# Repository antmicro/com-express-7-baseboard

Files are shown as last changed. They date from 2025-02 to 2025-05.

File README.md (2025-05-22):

# COM Express 7 Baseboard

Copyright (c) 2024-2025 [Antmicro](https://www.antmicro.com)




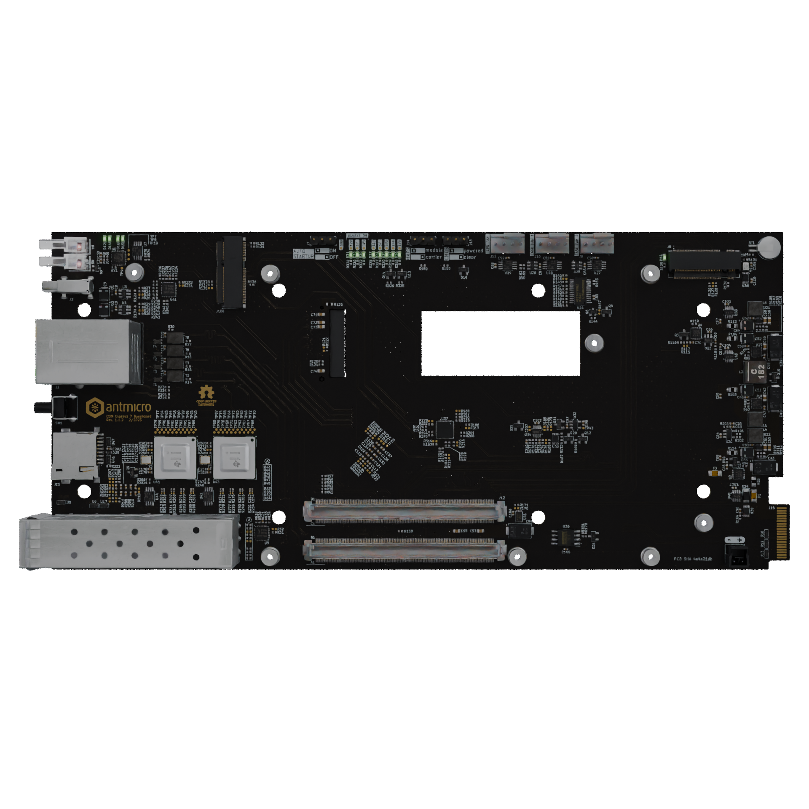
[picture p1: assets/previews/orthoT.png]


## Overview

This project contains open hardware design files for a baseboard supporting COM Express 7 modules.
The board breaks-out major communications and peripheral interfaces provided by the standard.
It also provides a backplane connector which makes it possible to integrate this board into larger systems.

## Key features

* Two SFP+ 10G Ethernet ports
* OCuLink PCIe x4 connector
* Two USB 3.0 type A ports
* Gigabit RJ45 connector
* Singular +12V supply voltage
* USB-C console output
* Two M.2 key M with PCIe x4
* M.2 key E
* SD card connector
* Backplane connector with PCIe, USB and UART console
* Temperature and fan monitor/controller with 3 12V fan connectors
* LEDs for status indication
* Board power/current monitors
* Board EEPROM and support for carrier MAFS BIOS

## Project structure

The main directory contains KiCad PCB project files, a LICENSE, and a README.
The remaining files are stored in the following directories:

* `doc` - contains board schematic and documentation
* `assets` - contains visual assets for showcasing this design on [Open Hardware Portal](https://openhardware.antmicro.com/boards/com-express-7-baseboard/?tab=features&view=top-ortho).

## Licensing

This project is published under the [Apache-2.0](LICENSE) license.

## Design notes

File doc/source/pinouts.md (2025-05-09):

# Pinouts

## Backplane connector ([`J16`](#J16))

```{csv-table}
:header: >
:    "Pin no.", "Net", "Pin no.", "Net"
:widths: 5, 20, 5, 20

"1", "12V","2", "12V"
"3", "12V","4", "12V"
"5", "12V","6", "12V"
"7", "12V","8", "12V"
"9", "12V","10", "12V"
"11", "GND","12", "GND"
"13", "GND","14", "GND"
"15", "GND","16", "GND"
"17", "PCIe TX0+","18","PCIe RX0-"
"19", "PCIe TX0-","20","PCIe RX0+"
"21", "GND","22", "GND"
"23", "PCIe TX1+","24","PCIe RX1+"
"25", "PCIe TX1-","26","PCIe RX1-"
"27", "GND","28", "GND"
"29", "PCIe REF.CK+","30", "!PERST"
"31", "PCIe REF.CK-","32", "!PRSNT"
"33", "GND","34", "GPIO"
"35","USB.D+","36","UART.RX"
"37","USB.D-","38","UART.TX"
"39", "GND","40", "GND"
```

## Fan connector ([`J9`](#J9), [`J10`](#J10), [`J11`](#J11))

```{csv-table}
:header: >
:    "Pin no.", "Net"
:widths: 5, 20

"1", "GND"
"2", "12V"
"3", "TACH"
"4", "PWM"
```

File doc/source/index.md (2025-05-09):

# {{project}}

```{toctree}
:maxdepth: 3

introduction
getting_started
power_supply
peripherals
pinouts
```

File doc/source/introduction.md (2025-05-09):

# Introduction

The `Baseboard` supports COM Express `Type 7` modules. The board breaks out major communications and peripheral interfaces as defined by the COM Express standard. It features front panel connectors for cable interfaces and a backplane edge connector designed for integrating the board into larger systems.

One of the supported COM Express Type 7 modules is the `SolidRun LX2160A`. It features 16 Arm Cortex-A72 processors, 4 x 10GbE and 18x PCIe Gen 3.0 lanes and is fully supported by Linux.

The board design files were created in `KiCad 8.x`.
You can find out more about the `COM Express 7 Baseboard` by visiting Antmicro's portals listed below:

* [Open Hardware Portal](https://openhardware.antmicro.com/boards/com-express-7-baseboard/)
* [System Designer](https://designer.antmicro.com/hardware/devices/com_express_7_baseboard_with_lx2160a)
* [Open Source Portal](https://opensource.antmicro.com/projects/com-express-7-baseboard/)
 
They provide 3D renders and the board [stackup definition](https://openhardware.antmicro.com/boards/com-express-7-baseboard/?view=top-ortho&tab=stackup), as well as [an interactive preview](https://openhardware.antmicro.com/boards/com-express-7-baseboard/?view=top-ortho&amp%3Btab=stackup&tab=preview) of the board schematic.
A [PDF schematic](../com-express-7-baseboard-schematic.pdf) of the board is also available.

## Block diagram

<iframe src="_static/COM_Express_baseboard_VSD_graph.html" style="border:0px" height="800px" width="100%" title="COM Express 7 baseboard graph"></iframe>

## IO map 

A map of on-board connectors, status LEDs, control buttons and I/O interfaces is provided below.

:::{figure-md}
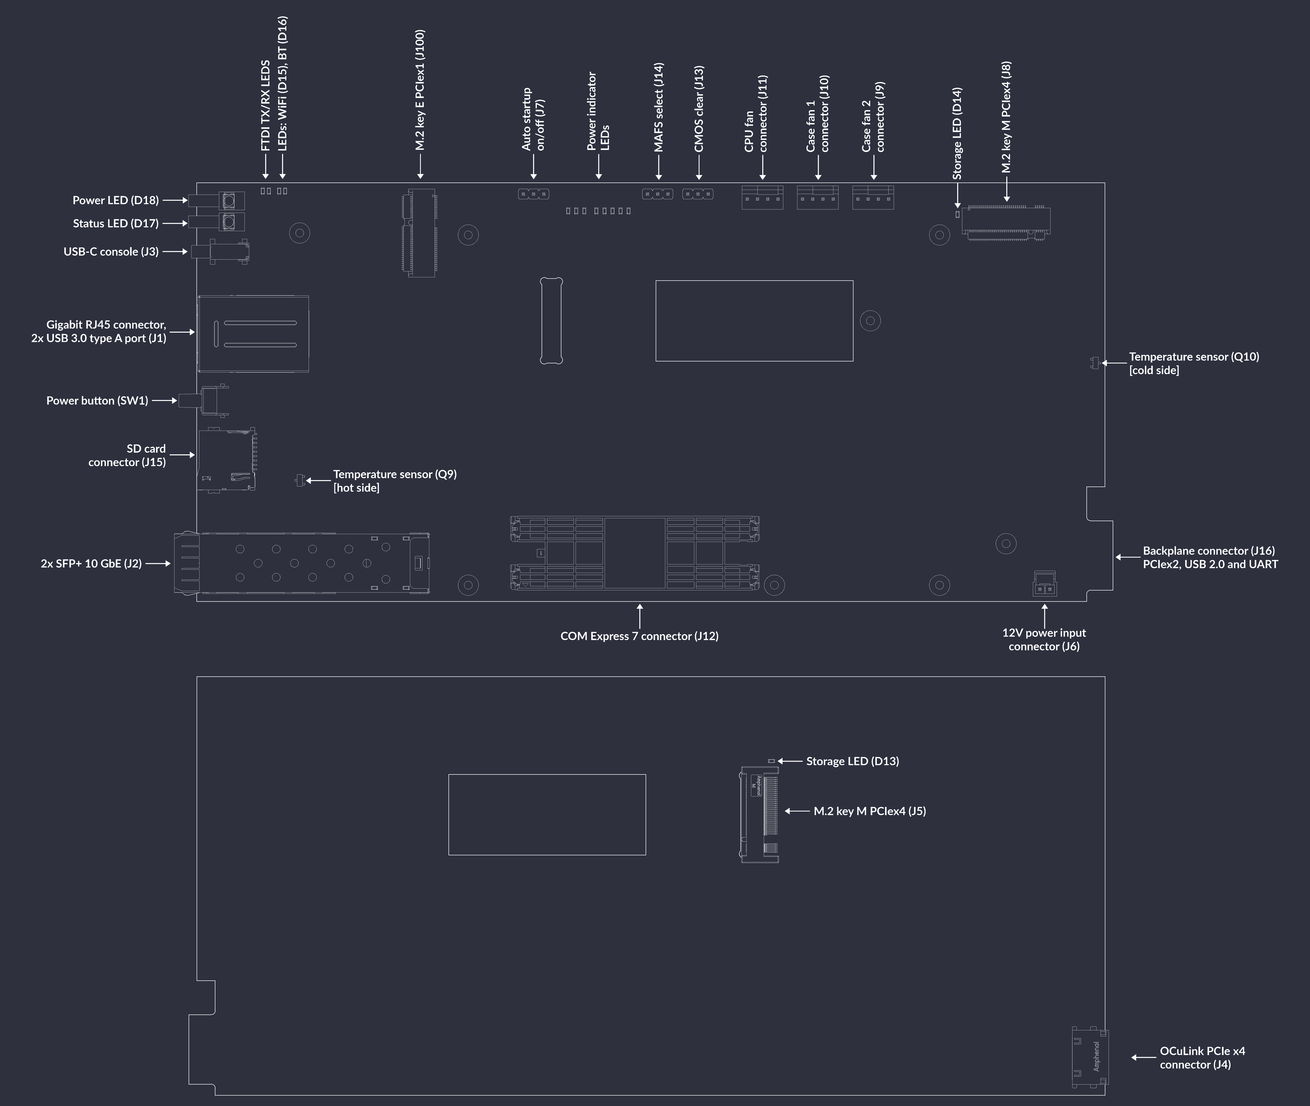
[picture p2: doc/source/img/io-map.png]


COM Express 7 Baseboard interface map
:::

## Power
 
`COM Express 7 Baseboard` can be powered with a DC voltage via the on-board locking DC connector ([`J6`](#J6)) with Molex Nano-Fit plug, or backplane PCB-edge connector ([`J16`](#J16)).
More details in [Power supply](./power_supply.md) section.

## Available interfaces and features

- 2x SFP+ 10 Gigabit Ethernet port ([`J2`](#J2))
- Gigabit Ethernet RJ45 connector ([`J1A`](#J1))
- OCuLink PCIe x4 connector ([`J4`](#J4))
- USB-C console ([`J3`](#J3))
- USB 3.0 - two type A ports: ([`J1B`](#J1)) and ([`J1C`](#J1))
- 2x M.2 2280 key M connector with PCIe x4 ([`J5`](#J5)) and ([`J8`](#J8))
- M.2 2230 key E connector with PCIe x1 and USB ([`J100`](#J100))
- Backplane PCB edge connector ([`J16`](#J16)) with PCIe x2, USB 2.0, UART console and 1x GPIO
- SD card connector ([`J15`](#J15))
- Board EEPROM and support for carrier MAFS BIOS
- Power button ([`SW1`](#SW1))
- Fan connectors: CPU fan ([`J11`](#J11)) + 2x case fan ([`J10`](#J10)) and ([`J9`](#J9))
- Board temperature sensors (`Q9`) and (`Q10`)
- 2x RGB LED for status indication

## Mechanics

The `COM Express 7 Baseboard` PCB is `227.5`x`104.0` millimeters (WxL) which translates into `8.96`x`4.09` inch.
The overall height of the set depends on the attached cooling module.

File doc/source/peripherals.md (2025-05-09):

# Peripherals

## Selection jumpers

- **Master Attached Flash Sharing location selection**

  MAFS location can be set to be on `module` or on `carrier`, using ([`J14`](#J14)) jumper.
  During normal operation, it is set to `module`.

- **Clear CMOS**

  Using ([`J13`](#J13)) jumper, RTC on COM Express 7 can be cleared.
  During normal operation, it is set to `powered`, which provides power to the RTC.

Jumpers positions for normal operation are shown on the render bellow.
:::{figure-md}
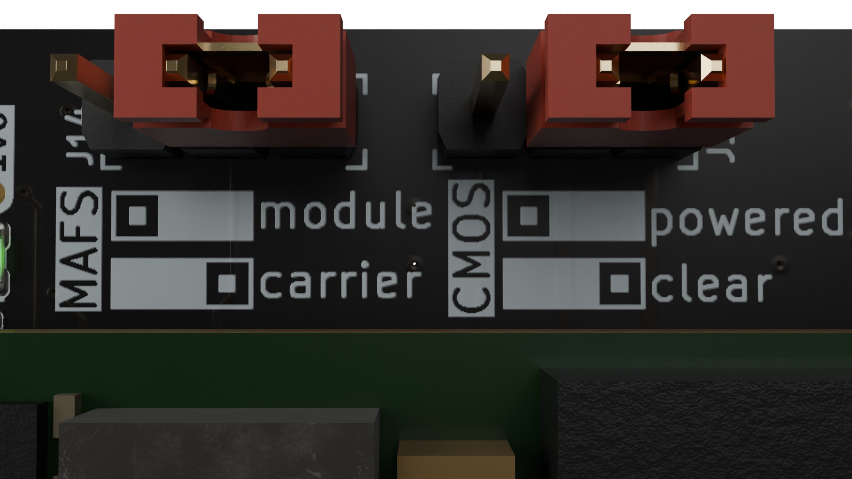
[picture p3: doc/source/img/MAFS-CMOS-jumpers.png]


COM Express 7 Baseboard MAFS and CMOS jumpers default configuration.
:::

## Fan control

- CPU fan ([`J11`](#J11)connector) is controlled by the COM Express 7 SoM<!-- (pins `B101`(PWM) and `B102`(TACH) of [`J12`](#J12))-->.
- Case fans ([`J10`](#J10) and [`J9`](#J9) connectors) can either share PWM speed control with CPU fan or be individually controlled by `ADT7476AARQZ` (`U24`).

## Board temperature measurement

Board temperature can be monitored with `ADT7476AARQZ` (`U24`) in three locations on the `COM Express 7 Baseboard`, using internal to the IC temperature sensor and two external sensors: (`Q9`) and (`Q10`). Their location is shown on the picture bellow.

:::{figure-md}
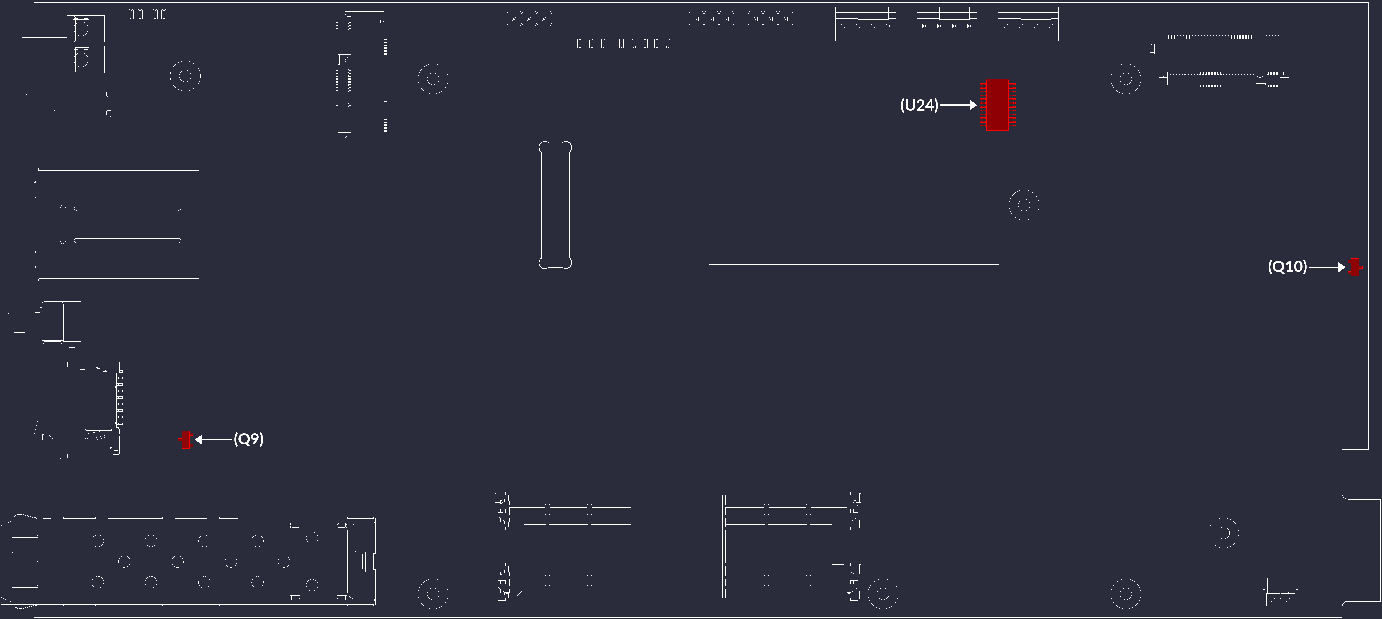
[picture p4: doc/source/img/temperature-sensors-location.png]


COM Express 7 Baseboard location of temperature sensors.
:::

## SFI / KR

1 HS channel needs to be configured (e.g. CH A) for 10G-KR, configure the other HS channel for XFI per the attached instructions,  and use Data Switch to connect CH A to CH B (DST_CONTROL_1/2 registers) [(attached instructions)](https://e2e.ti.com/support/interface-group/interface/f/interface-forum/703878/tlk10034-10gbase-kr-to-sfi-sfp).

By using `OR` resistors, `SFI` can be directly connected to `10GBase-KR` pins on `COM Express Type 7`, eliminating the need for the `TLK10232CTR` ICs. This configuration is intended for modules that support SFI-compatible interfaces on 10GBase-KR pins, such as the `SolidRun LX2160A`.

````{tab} Default configuration

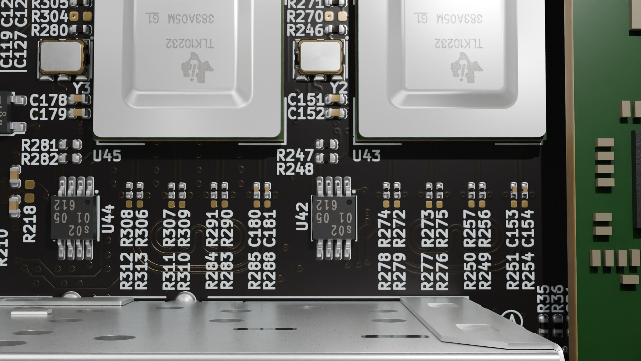
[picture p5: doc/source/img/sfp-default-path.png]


````
````{tab} TLK10232CTR bypassed

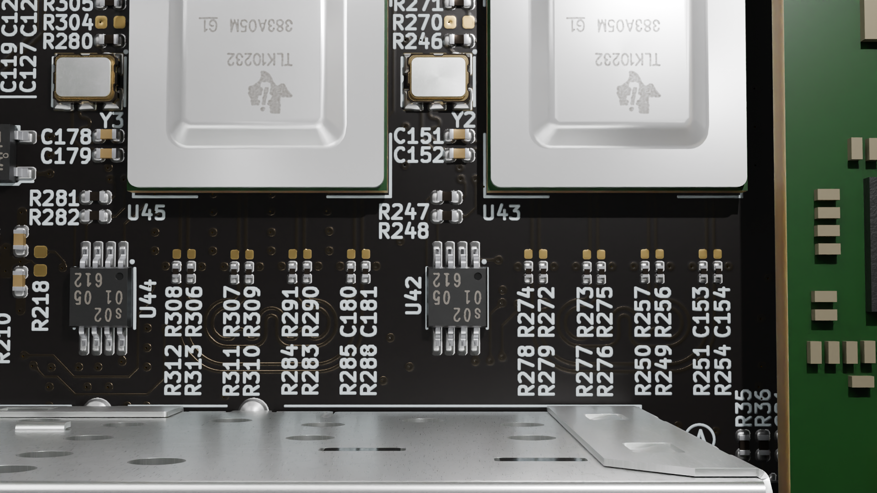
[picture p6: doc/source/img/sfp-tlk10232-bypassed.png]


````

## 10GbE on backplane connector

If `LX2160A` SoM is used, `PCIe B3x4` on the backplane connector ([`J16`](#J16)) can be configured as `10G-KR`.

## GPIO Expanders
Two `PCA9539AHF` GPIO expanders are connected to the I2C `bus 1` of the SoM:

- Expander at Address `0x74` (`U41`)

| **Pin**  | **Function** | **Details** |
|---|---|---|
| P0_0 | RGB LED - Green | `D17` |
| P0_1 | RGB LED - Blue | `D17` |
| P0_2 | RGB LED - Red | `D17` |
| P0_3 | USB Power Enable - `EN_1` | ([`J1B`](#J1)) |
| P0_4 | USB Power Enable - `EN_2` | ([`J1C`](#J1)) |
| P0_5 | `!PRSNT` / `!CPRSNT0` | PCIe Redriver / OCuLink |
| P0_6 | `GPIO` | Backplane Connector ([`J16`](#J16)) |
| P0_7 | `!PRSNT` | Backplane Connector ([`J16`](#J16)) |

- Expander at Address `0x75` (`U5`)

| **Pin**  | **Function** | **Details** |
|---|---|---|
| P0_0 | SFP0 LED - Yellow | `J2` |
| P0_1 | SFP0 LED - Green | `J2` |
| P0_3 | SFP1 LED - Yellow | `J2` |
| P0_4 | SFP1 LED - Green | `J2` |

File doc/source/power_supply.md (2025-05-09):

# Power supply

## Power input connectors
The `COM Express 7 Baseboard` supports two power supply scenarios: 

* `DC locking connector` ([`J6`](#J6)) which accepts a 2-wire `Molex Nano-Fit` plug.

  This is the easiest and most recommended solution for starters.
  You can use an off-the-shelf Nano-Fit Cable assembly (Molex/[451300203](https://www.molex.com/en-us/products/part-detail/451300203)) or build a custom one from a Nano-Fit receptacle (Molex/[1053071202](https://www.molex.com/en-us/products/part-detail/1053071202)) and pre-crimped wires (Molex/[797582130](https://www.molex.com/en-us/products/part-detail/797582130)). 
  The COM Express 7 Baseboard can be powered with a benchtop PSU or AC/DC wall adapter providing 12V DC with at least 60W.
  If you are using a DC locking connector - please observe the polarity marked in the render below.

:::{figure-md}
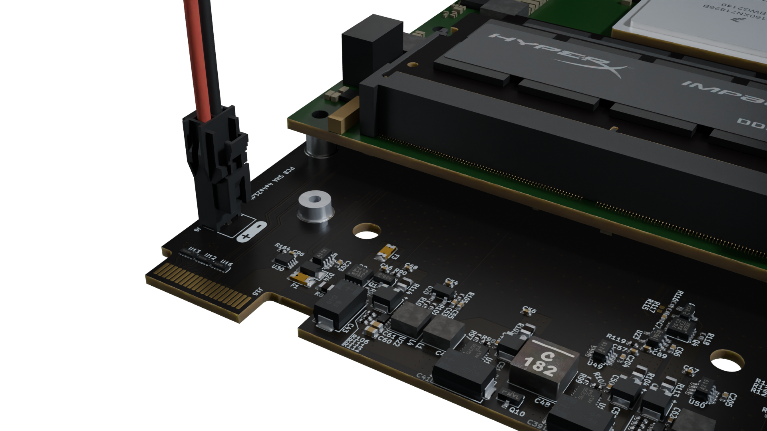
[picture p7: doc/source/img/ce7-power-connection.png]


COM Express 7 Baseboard DC power connection with polarity marking (red: VCC, black: GND).
:::

* `Backplane PCB-edge connector` ([`J16`](#J16)) is designed to interface with `Samtec HSEC8 2x20 HSEC8-120-01-S-D-EM2` female connector.
  This connector has the same electrical requirements as the DC locking connector, since they are directly connected with each other on the baseboard.
  See the [Pinouts](./pinouts.md) section for the connector pinout.

These inputs are protected with a 12A fuse and 15V TVS diode. The nominal supply voltage is 12V. 
When LX2160A is used, absolute maximum is 15V and it requires 50W full system.

## Auto startup

[`J7`](#J7) jumper determines if auto startup is on/off.

When auto startup is enabled, all power rails of the `COM Express 7 Baseboard` turn on automatically after power is provided to the baseboard, and the SoM boots.

If auto startup is off, only the always on (AON) rails turn on after power is provided to the baseboard.
Then to continue the power up, power button [`SW1`](#SW1) needs to be pressed.

## Power sequence

```{md-mermaid}
graph LR
V_IN --> +12V_AON --> +5V_AON --> +3V3_AON --> Power_button/auto_startup -->  +12V --> +5V --> +3V3 --> +1V8 --> +1V0 -->|120ms| PWR_OK
```

- When 12V is supplied to the baseboard, LED [`D18`](#D18) glows red, indicating that power is connected
- After all power supplies start-up correctly, 1V0 rail will trigger `PWR_OK` line to set to high state after 120ms (the delay is created by `U20`). 
This will result in ([`D18`](#D18)) changing color from red to green, which signals successful power supply section startup.
- There is a combinational logic circuit which pulls the `PSON` net low, if the COM Express module is NOT type 7. It is determined by the state of `!TYPE0`, `!TYPE1` and `!TYPE2` signals, which come from the connected COM Express module (pins C54, C57 and D57 of [`J12`](#J12)). This will prevent the baseboard from powering up, if wrong type of COM Express module is connected.

## Power indicator LEDs

There are power indicator LEDs for every power rail (`D26`, `D27`, `D28`, `D30`, `D31`, `D32`, `D33` and `D34`) as shown on the render below.

:::{figure-md}
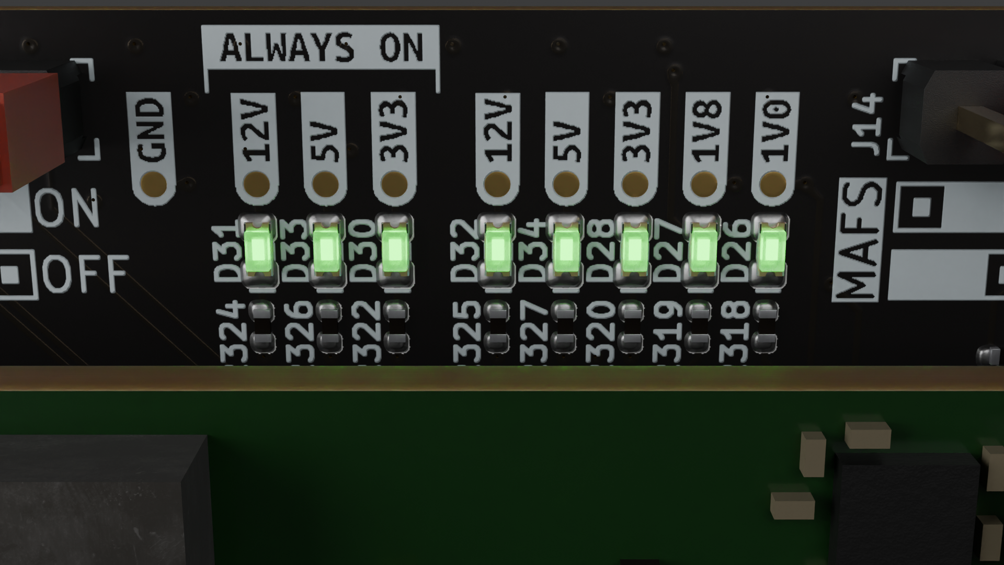
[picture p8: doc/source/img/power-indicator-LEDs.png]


COM Express 7 Baseboard power indicator LEDs.
:::

## Supply monitoring
- Three `INA219AIDCNR` ICs are used to monitor voltage and current draw on `12V` input, `3V3` and `5V` rails.
They are connected to I2C `bus 1` of the SoM. Their I2C addresses and corresponding power rails are listed below:

  | Address  | Description |
  |----------|-------------|
  | 0x40     | 12V rail    |
  | 0x41     | 3V3 rail    |
  | 0x42     | 5V  rail    |

- `ADT7476AARQZ` IC is used to monitor voltage of `1V0`, `1V8`, `3V3`, `5V0` and `12V` rails. It is also connected to I2C `bus 1` of the SoM, and its address is `0x2D`.
The voltage readings can be accessed through the following register addresses:

  | Register | Description |
  |----------|-------------|
  | 0x20     | 1V0 reading |
  | 0x21     | 1V8 reading |
  | 0x22     | 3V3 reading |
  | 0x23     | 5V  reading |
  | 0x24     | 12V reading |

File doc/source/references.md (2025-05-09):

# Image references
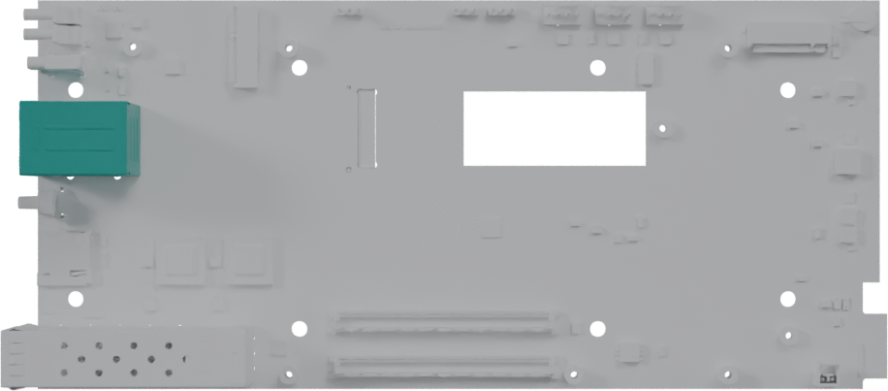
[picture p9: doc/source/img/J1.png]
```{image} img/J1.png
   :name: J1
```
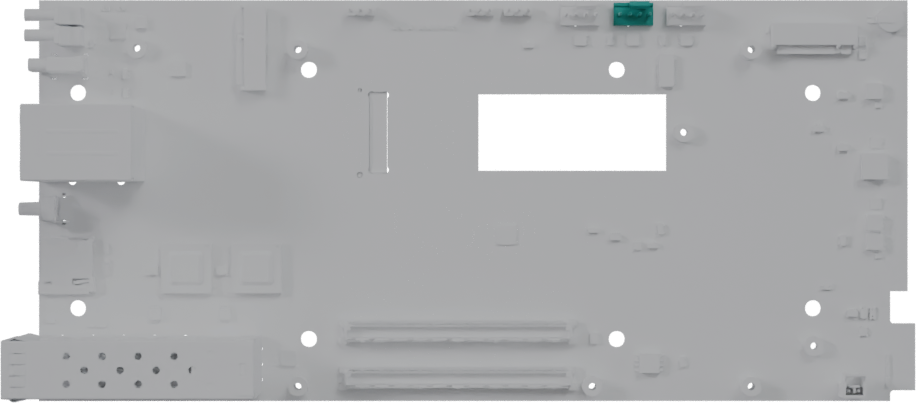
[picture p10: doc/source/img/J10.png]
```{image} img/J10.png
   :name: J10
```
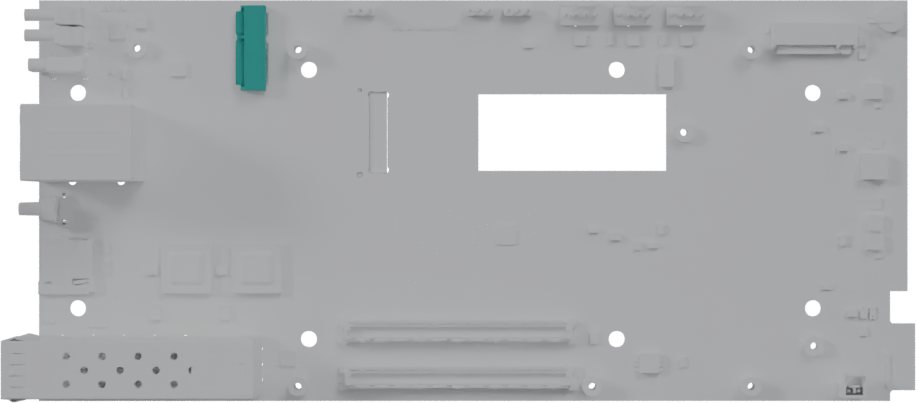
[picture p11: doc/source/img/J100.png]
```{image} img/J100.png
   :name: J100
```
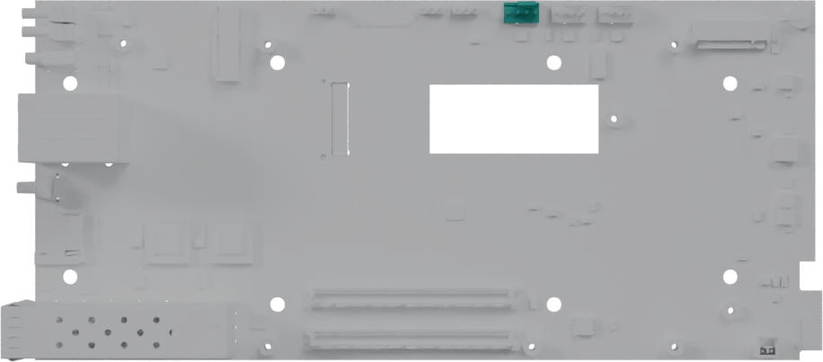
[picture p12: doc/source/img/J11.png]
```{image} img/J11.png
   :name: J11
```
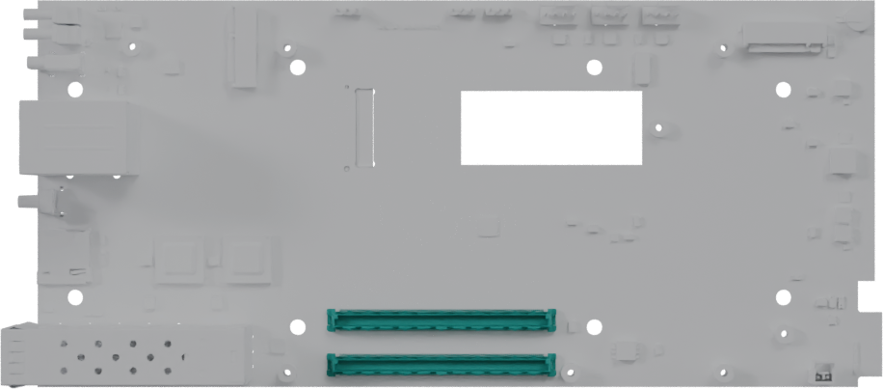
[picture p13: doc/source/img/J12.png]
```{image} img/J12.png
   :name: J12
```
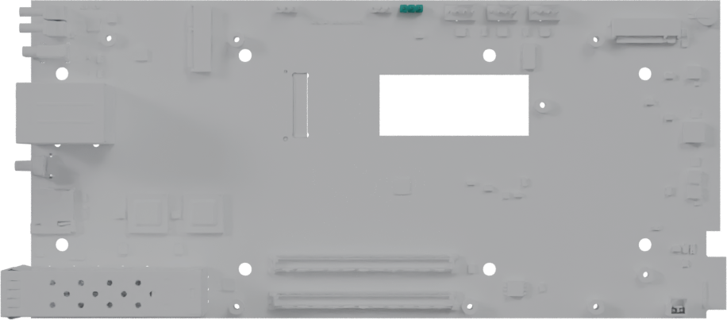
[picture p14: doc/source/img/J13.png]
```{image} img/J13.png
   :name: J13
```
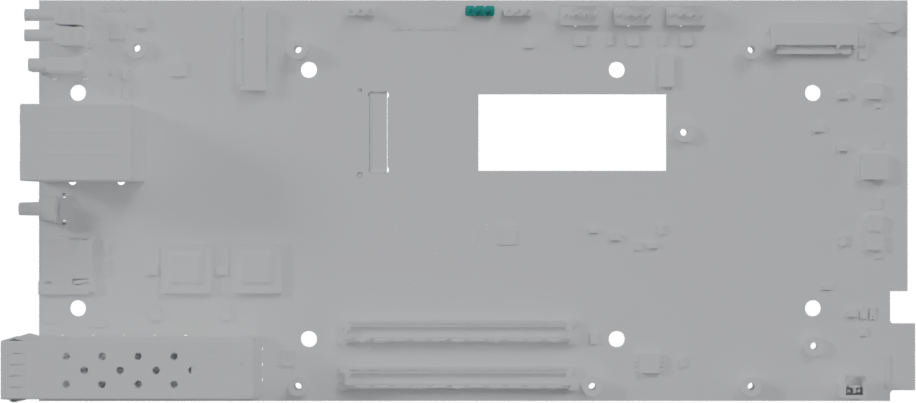
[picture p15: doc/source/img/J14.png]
```{image} img/J14.png
   :name: J14
```
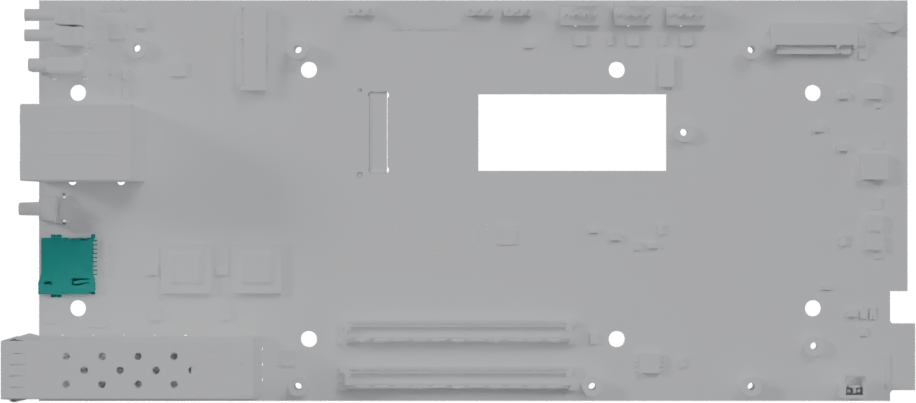
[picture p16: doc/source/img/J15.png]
```{image} img/J15.png
   :name: J15
```
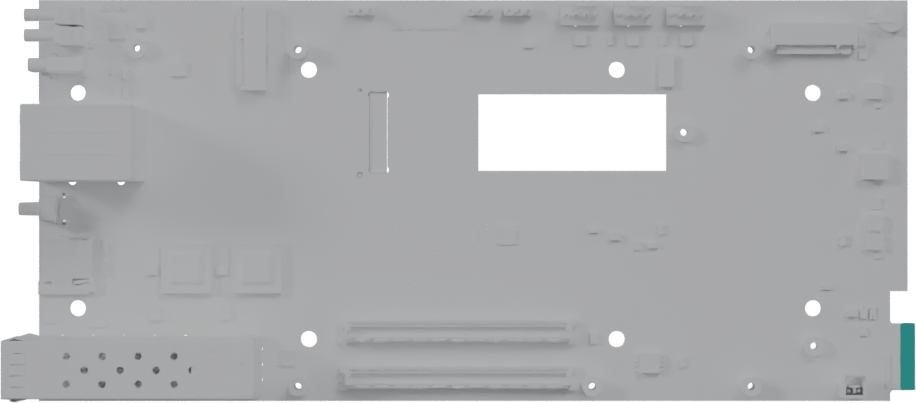
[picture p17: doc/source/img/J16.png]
```{image} img/J16.png
   :name: J16
```
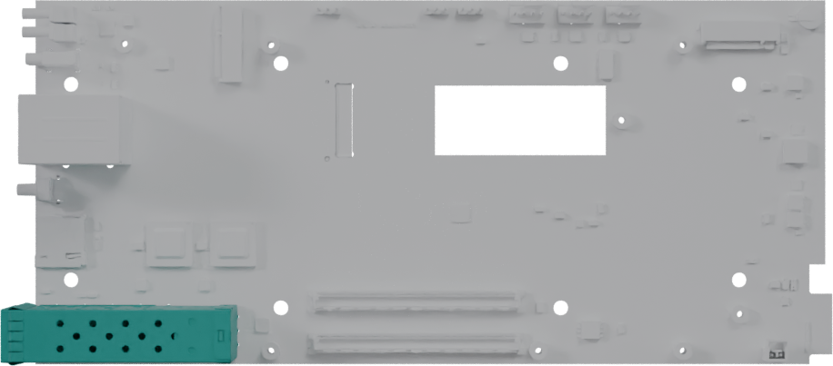
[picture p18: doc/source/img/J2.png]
```{image} img/J2.png
   :name: J2
```
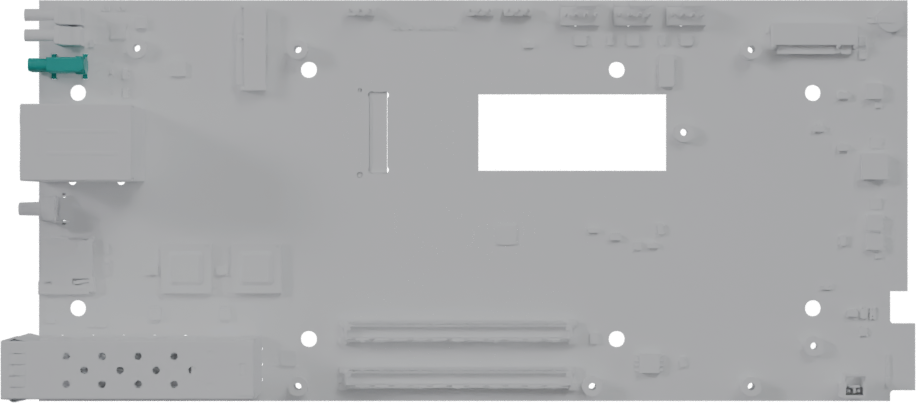
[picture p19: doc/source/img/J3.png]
```{image} img/J3.png
   :name: J3
```
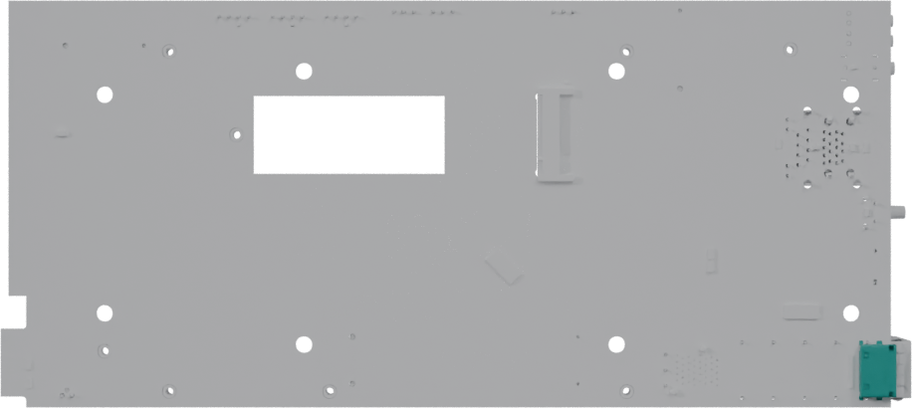
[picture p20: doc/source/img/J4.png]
```{image} img/J4.png
   :name: J4
```
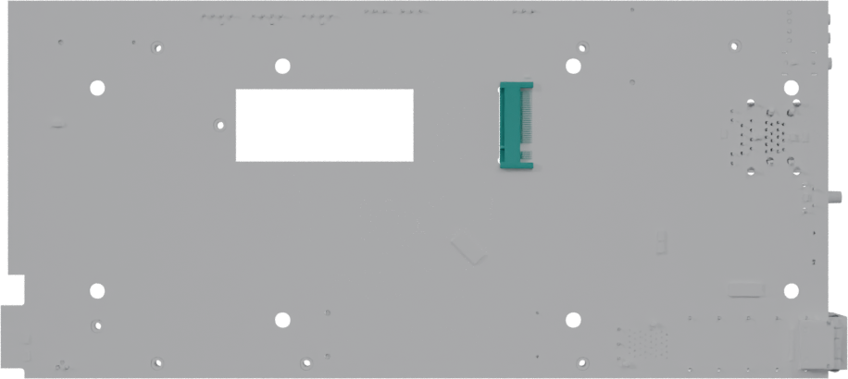
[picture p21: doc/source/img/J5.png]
```{image} img/J5.png
   :name: J5
```
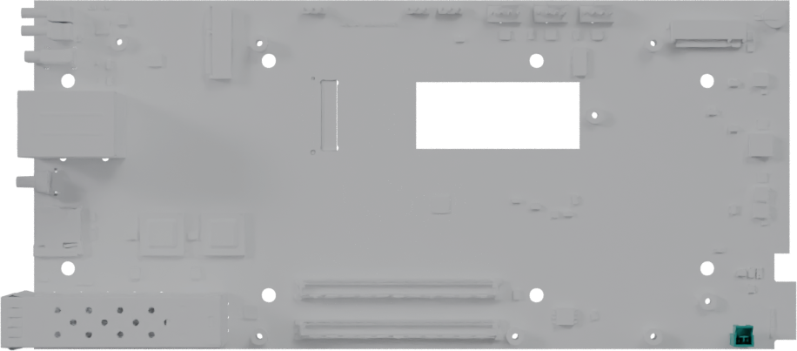
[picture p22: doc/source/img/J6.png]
```{image} img/J6.png
   :name: J6
```
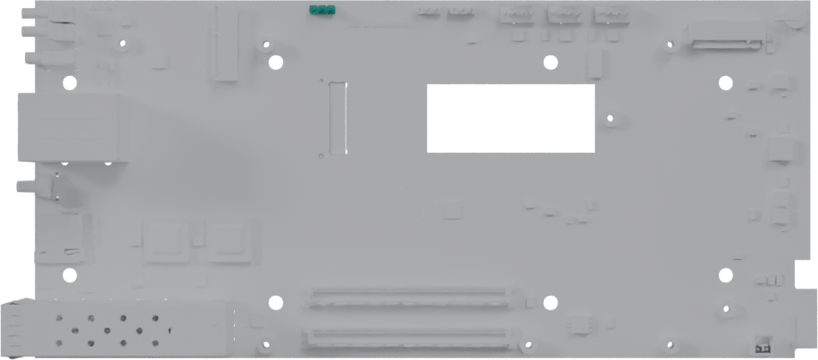
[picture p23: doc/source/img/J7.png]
```{image} img/J7.png
   :name: J7
```
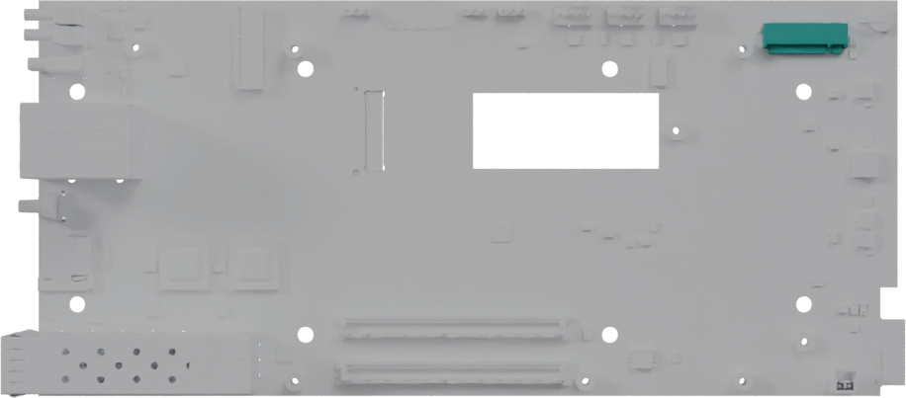
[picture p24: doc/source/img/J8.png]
```{image} img/J8.png
   :name: J8
```
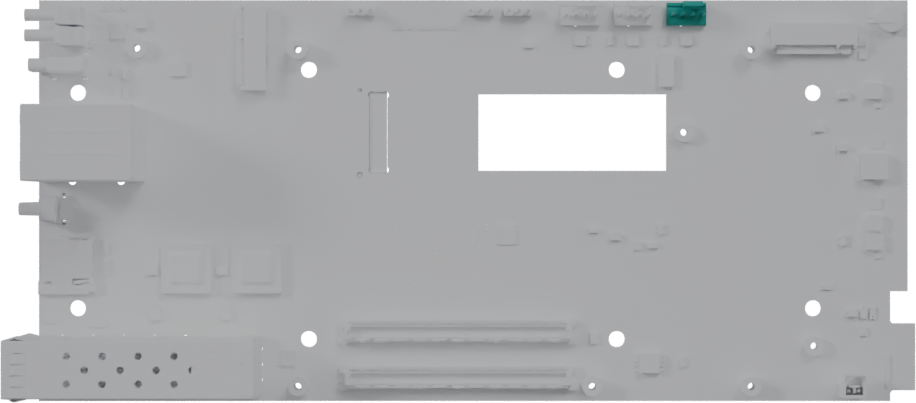
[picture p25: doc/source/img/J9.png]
```{image} img/J9.png
   :name: J9
```
```{image} img/SW1.png
   :name: SW1
```

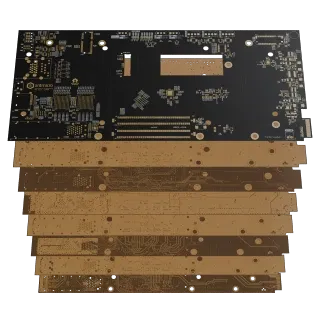
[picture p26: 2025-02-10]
assets/previews/layer1_thumbnail.webp

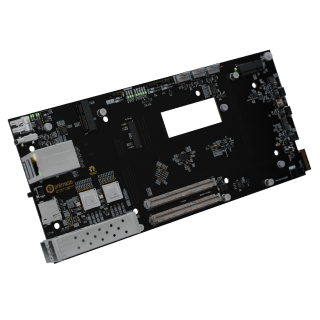
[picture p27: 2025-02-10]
assets/previews/leftT_thumbnail.png

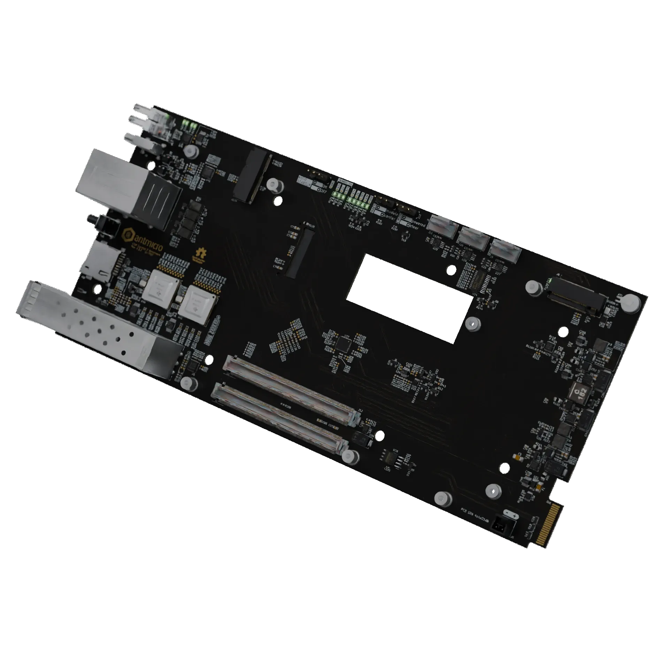
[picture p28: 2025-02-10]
assets/previews/rightT.webp

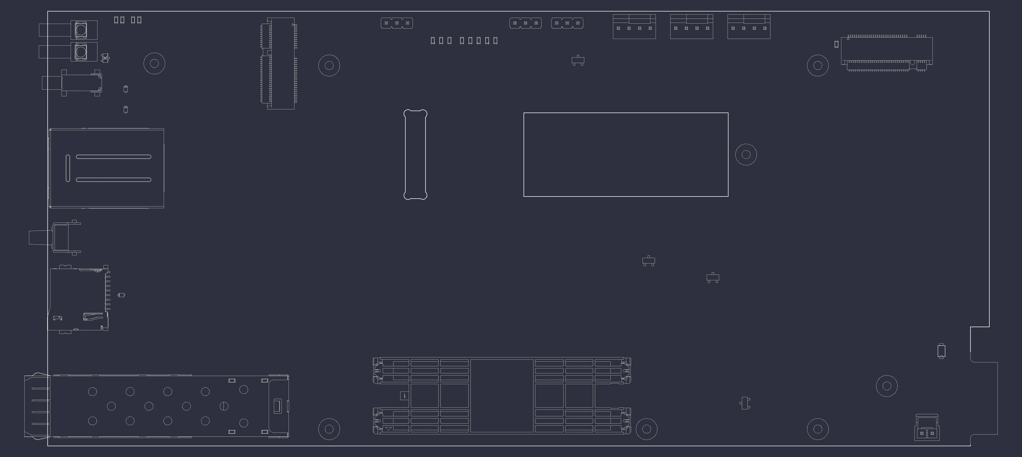
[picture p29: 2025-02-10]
assets/wireframe/wireframe_descriptions_top.webp

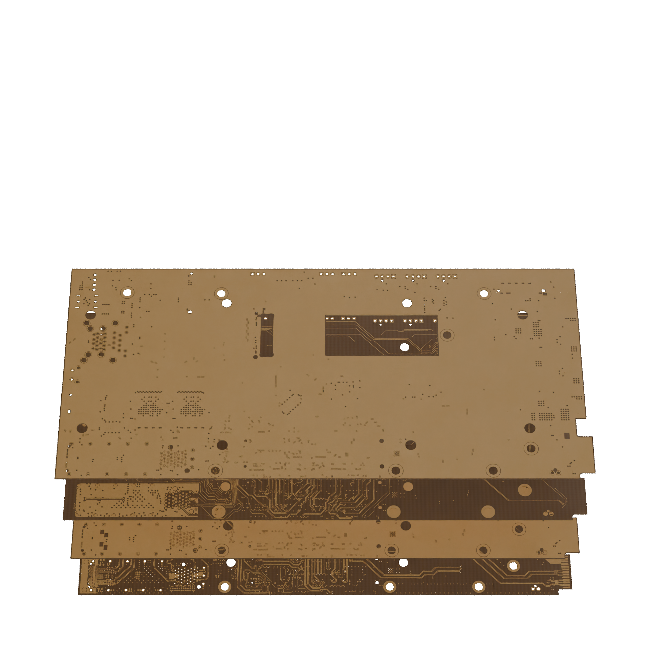
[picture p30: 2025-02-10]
assets/previews/layer6.png

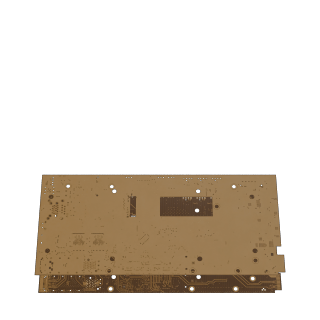
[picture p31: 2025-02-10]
assets/previews/layer8_thumbnail.png

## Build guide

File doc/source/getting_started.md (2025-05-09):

# Getting started guide

This manual will guide you through the initial setup of the open hardware `COM Express 7 Baseboard`. It describes the basic steps required to assemble the board with required peripheral accessories, write a compiled Board Support Package (BSP) to the processing module and get it booted. If you want to learn more about the `COM Express 7 Baseboard` itself, go to the [Introduction](./introduction.md) section. That section also includes an I/O map that may come in handy when locating interface connectors mentioned in this guide.
 
## Collect the hardware

To get started with the `COM Express 7 Baseboard`, you’ll need the following hardware:

### 1. COM Express 7 SoM
The `COM Express 7 Baseboard` is compatible with COM Express `Type 7` modules. The provided reference BSP has been developed for `SolidRun LX2160A` (SRX2160S01D00GE064V21C0)<!-- but it should work with other Type 7 modules as well -->.

### 2. RAM modules
You will need 2 `SO-DIMM DDR4 RAM` modules. Check the [list](https://solidrun.atlassian.net/wiki/spaces/developer/pages/197494332/LX2160A+COM+Tested+SO-DIMM+Memory) of tested modules, to help you choose appropriate RAM modules.

### 3. Power supply

The `COM Express 7 Baseboard` supports two power supply scenarios: 

* `DC locking connector` ([`J6`](#J6))
* `Backplane PCB-edge connector` ([`J16`](#J16))

More details in [Power supply](power_supply.md) chapter.

### 4. Fastening bolts

You will need five metric M2.5 (5mm long) bolts and a matching screwdriver to mount the SoM to the baseboard.
All mechanical fastening points located on the board support bolts with metric M2.5 thread (ISO 7045).

### 5. Micro SD card

Micro SD card with capacity of at least 4GB is needed, to transfer the BSP image to the baseboard.

### 6. Host PC

You will need a computer running Linux for flashing the reference BSP image to the SD card. 
The BSP flashing instructions provided below were verified with Debian based systems.
You may need to introduce minor adjustments for other Linux distributions.

### 7. SD card reader

You will need to be able to connect the micro SD card to your PC.
If your PC doesn't have an integrated SD card reader, you will need an external one.

### 8. Cabling

You will need a USB-C cable for connecting your PC to the USB-C port ([`J3`](#J3)) located on the baseboard.
This connection will provide access to the SoM's terminal on your PC.

Ethernet cable will be needed to provide internet connection to the `COM Express 7 Baseboard` via ([`J1A`](#J1)).

## Flash the SD card with system image

<!-- Instructions are from this [guide](https://solidrun.atlassian.net/wiki/spaces/developer/pages/197494288/HoneyComb+LX2+ClearFog+CX+LX2+Quick+Start+Guide). -->

### 1. Download a pre-built snapshot

Download this [pre-built snapshot image](https://solid-run-images.sos-de-fra-1.exo.io/LX2k/lx2160a_build/ls-5.15.71-2.2.0/2024-11-26_d5645d3/lx2160a_rev2_cex7_honeycomb_2000_700_2900_18_5_2-d5645d3.img.xz).

**NOTE:** This is a stock BSP, which doesn't support all functionalities of the `COM Express 7 Baseboard`.

### 2. Write the BSP image to the SD card

Plug the micro SD into your Linux PC. The following assumes that the micro SD is added as `/dev/sdX` and all it’s partitions are unmounted. In the terminal, run `sudo mount`, to check if the SD card is mounted. It can appear as /dev/mmcblk0p1 or /dev/sdb1 or similar. If partitions are mounted, unmount them first: `sudo umount <mount point>` (eg. `sudo umount /dev/sdc1`).
Now the image can be flashed to the SD card. 

Use this command for writing the image to an SD card (remember to use proper path to the BSP image and SD card):
`sudo xz -dc lx2160a_....img.xz | sudo dd of=/dev/sdX bs=4M conv=fsync`.

## Build your setup

To prepare the `COM Express 7 Baseboard` for initial usage, follow the steps described below: 

### 1. Install the RAM modules

Begin with installing the RAM modules on the COM Express 7 SoM.

### 2. Install the SoM

Securely attach the COM Express 7 SoM to the [`J12`](#J12) connector of the `COM Express 7 Baseboard`.
Fasten the SoM to the baseboard with five metric M2.5 (5mm long) bolts.
Remember to connect the cooling fan plug into the [`J11`](#J11) fan receptacle. 

### 3. Insert micro SD card

Insert the micro SD card containing the BSP, to the `COM Express 7 Baseboard` micro SD card slot ([`J15`](#J15)).

### 4. Select boot source

Configure the SW1 switch on the COM Express 7 SoM as shown on the image bellow.

:::{figure-md}
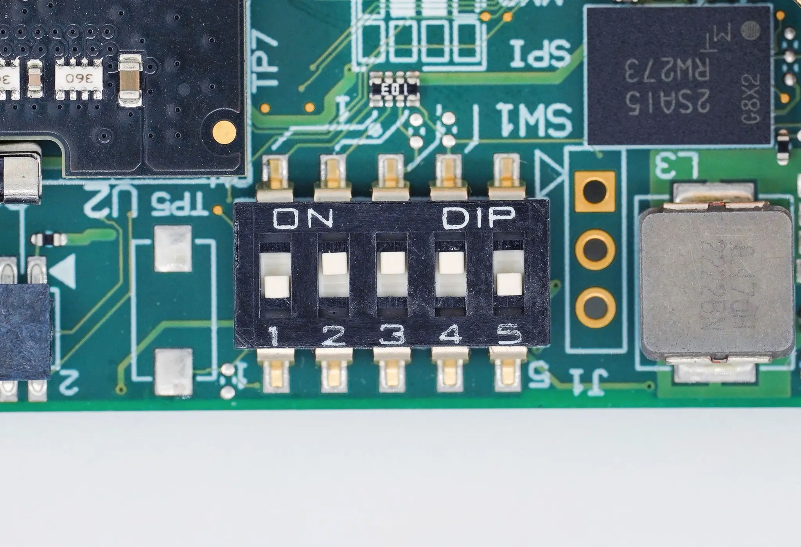
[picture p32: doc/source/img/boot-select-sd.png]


COM Express 7 boot source configured to SD card 
:::

<div align="center">

| Switch 1 | Switch 2 | Switch 3 | Switch 4 | Switch 5 |
|---|---|---|---|---|
| OFF | ON | ON | ON | x |

</div>

### 5. Connect the Ethernet port.

Connect the `COM Express 7 Baseboard` to the internet network using `RJ45` cable connected to [`J1A`](#J1) Ethernet port.

### 6. Connect the debug console

Connect the debug USB-C ([`J3`](#J3)) port to your PC. 
This should get a virtual USB/serial port registered in your system under ``/dev/ttyUSBx``.
You can check the ``lsusb`` or ``dmesg`` commands to verify if the serial bridge was enumerated properly.

:::{figure-md}
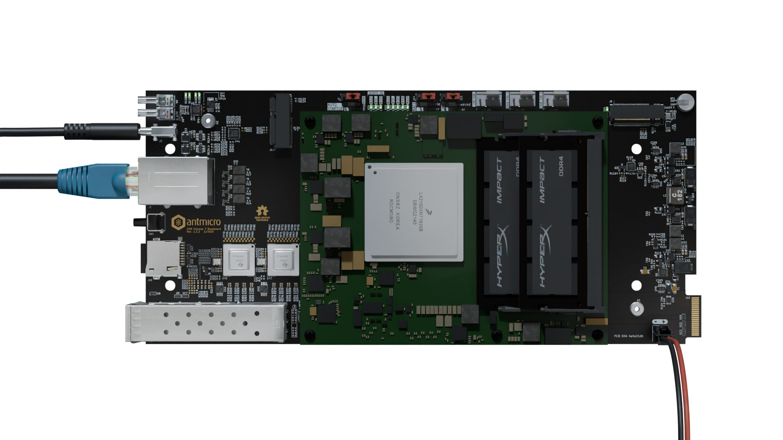
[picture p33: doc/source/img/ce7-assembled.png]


COM Express 7 Baseboard ready for flashing (SoM heat sink and fan not shown).
:::

## Flash the BSP image

The following steps will guide you through the process of flashing a precompiled Board Support Package (BSP) for the `COM Express 7 Baseboard`.

### 1. Open debug console

Whenever developing with the `COM Express 7 Baseboard`, it always makes sense to have a terminal hooked to the Debug UART on your host PC.
You can use any serial port terminal emulator for that, but we’ll use ``picocom`` in this guide.
Make sure that the [debug console USB](#connect-the-debug-console) is connected to your host PC and the USB-serial converter is enumerated:
```{code-block} bash
:emphasize-lines: 1,3

lsusb -d 0403:
# Bus 001 Device 118: ID 0403:6015 Future Technology Devices International, Ltd Bridge(I2C/SPI/UART/FIFO)
sudo dmesg | grep FTDI
# [1740634.745814] usb 1-4: FTDI USB Serial Device converter now attached to ttyUSB0
```

Run in the terminal:
```bash
sudo picocom -b 115200 /dev/ttyUSB0
```

<!-- You should keep the ``picocom`` terminal open in a separate window/tab throughout board flashing.
That will give you an insight into the progress and debug log messages displayed during the process. -->

### 2. Apply power

Pick one of the power supply scenarios described in the [Power Supply](#power-supply) section. 
We recommend using the DC locking connector ([`J6`](#J6)).
Apply power to the board.

Providing valid power supply should cause the ([`D18`](#D18)) power indicator LED to light up green.
*(That is if auto startup is enabled, otherwise you need to press the [`SW1`](#SW1) power button. More on that in the [Power supply](power_supply.md) chapter.)*

The SoM should start booting up, and you should see booting information on the `picocom` console.

### 3. Flash to eMMC

Stop the u-boot count down by clicking any key in the `picocom` console.

To flash to eMMC run the following commands (it will wipe your data on the eMMC device).
```bash
load mmc 0:1 0xa4000000 ubuntu-core.img
mmc dev 1
mmc write 0xa4000000 0 0xd2000
```

Boot the machine by running `boot`

### 4. Login

The SoM should boot up to the login screen visible in the debug console.
The reference BSP comes with a preconfigured root account.

Use the following login credentials to get access to the system:

```
localhost login: root
password: root
```

### 5. Finalize configuration

Using SW1 switch on the COM Express 7 SoM, configure it to boot from eMMC (change switch 4 to OFF), as shown on the image bellow.

:::{figure-md}
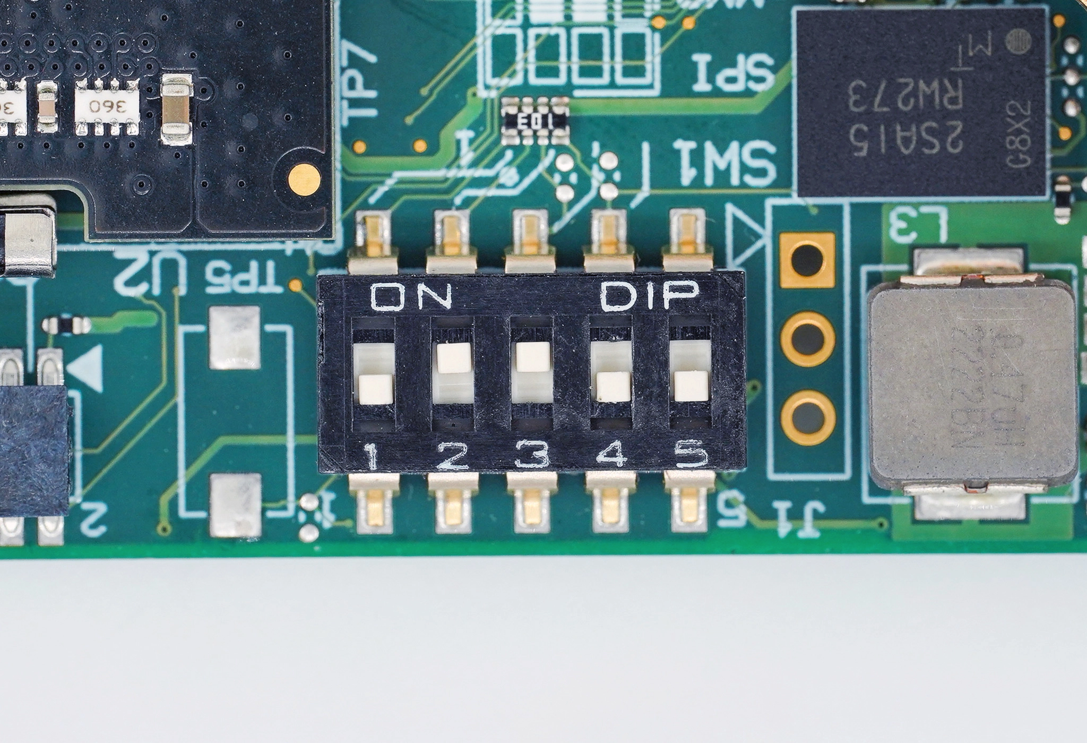
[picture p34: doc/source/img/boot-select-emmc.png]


COM Express 7 boot source configured to eMMC
:::

<div align="center">

| Switch 1 | Switch 2 | Switch 3 | Switch 4 | Switch 5 |
|---|---|---|---|---|
| OFF | ON | ON | OFF | x |

</div>

Remove the micro SD card from the baseboard (this will make it easier to find the path for eMMC).

- Check location of the eMMC: `lsblk | grep mmcblk`. It should show up as `mmcblkX`, where `X` is an integer.

- Run `fdisk /dev/mmcblkX`.

- Recreate the first partition by deleting it and then creating a new partition that starts at block 131072 and extends to the end of the drive (or less depending on your needs).

- Write the new partition, when prompted `Do you want to remove the signature?`, answer with `No`.

- Run `resize2fs /dev/mmcblkXp1`.

Example execution of these commands is shown bellow (when no command was given, `Enter` was pressed).

```{code-block} bash
:emphasize-lines: 1, 6,16, 21, 29, 33, 36, 37, 38, 43, 45, 50
root@localhost:~# lsblk | grep mmcblk
mmcblk1      179:32   0 59.2G  0 disk
└─mmcblk1p1  179:33   0  350M  0 part /
mmcblk0boot0 179:64   0    4M  1 disk
mmcblk0boot1 179:96   0    4M  1 disk
root@localhost:~# fdisk /dev/mmcblk1

Welcome to fdisk (util-linux 2.37.2).
Changes will remain in memory only, until you decide to write them.
Be careful before using the write command.

This disk is currently in use - repartitioning is probably a bad idea.
It`s recommended to umount all file systems, and swapoff all swap
partitions on this disk.

Command (m for help): d

Selected partition 1
Partition 1 has been deleted.

Command (m for help): p
Disk /dev/mmcblk1: 59.22 GiB, 63585648640 bytes, 124190720 sectors
Units: sectors of 1 * 512 = 512 bytes
Sector size (logical/physical): 512 bytes / 512 bytes
I/O size (minimum/optimal): 512 bytes / 512 bytes
Disklabel type: dos
Disk identifier: 0x30303030

Command (m for help): n
Partition type
   p   primary (0 primary, 0 extended, 4 free)
   e   extended (container for logical partitions)
Select (default p):

Using default response p.
Partition number (1-4, default 1):
First sector (2048-124190719, default 2048): 131072
Last sector, +/-sectors or +/-size{K,M,G,T,P} (131072-124190719, default 124190719):

Created a new partition 1 of type 'Linux' and of size 59.2 GiB.
Partition #1 contains a ext4 signature.

Do you want to remove the signature? [Y]es/[N]o: N

Command (m for help): w

The partition table has been altered.
Syncing disks.

root@localhost:~# resize2fs /dev/mmcblk1p1
resize2fs 1.46.5 (30-Dec-2021)
Filesystem at /dev/mmcblk1p1 is mounted on /; on-line resizing required
old_desc_blocks = 3, new_desc_blocks = 474
The filesystem on /dev/mmcblk1p1 is now 62029824 (1k) blocks long.

```

- Run `dhclient` in order to enable internet access.

- Update the RTC clock by running `ntpdate pool.ntp.org` and then `hwclock -w`.

- Run `apt-get update && apt-get upgrade -y` and then populate the root filesystem as you wish.

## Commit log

2024-10-23 [#56643] Add necessary blocks to schematic
    [2xSFP+.kicad_sch, backplane.kicad_sch, com-express-7-baseboard.kicad_pcb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]
2024-10-23 [#56643] Create buses for interfaces, assign buses to blocks
    [2xSFP+.kicad_sch, backplane.kicad_sch, com-express-7-baseboard.kicad_sch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]
2024-10-23 [#57056] Create schematics for M.2 and OCuLink connectors
    [2xSFP+.kicad_sch, com-express-7-baseboard.kicad_sch, com_express_7_interfaces.kicad_sch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]
2024-10-23 [#57056] Add PCIe circuitry
    [com-express-7-baseboard.kicad_sch, pcie_misc.kicad_sch]
2024-10-23 [#57056] Add USB-C console
    [com-express-7-baseboard.kicad_sch, usb-c_console.kicad_sch]
2024-10-23 [#57056] Add ESD diodes to OCuLink
    [oculink.kicad_sch]
2024-10-23 [#57056] Connect USB 3.0 connectors on combo connector
    [com-express-7-baseboard.kicad_sch, usb3+rj45.kicad_sch]
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2024-10-23 [#57056] Update top sheet, update sheet's dates
    [2xSFP+.kicad_sch, backplane.kicad_sch, com-express-7-baseboard.kicad_sch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]
2024-10-23 [#57056] Update PCIe lane assignment, drop 2nd OCuLink
    [backplane.kicad_sch, com-express-7-baseboard.kicad_sch, com_express_7_interfaces.kicad_sch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]
2024-10-23 [#57056] Update GPIO assignment
    [com-express-7-baseboard.kicad_sch, com_express_7_interfaces.kicad_sch, usb3+rj45.kicad_sch]
2024-10-23 [#57056] Add GPIO expander. Connect GPIOs and SMBus lines
    [com-express-7-baseboard.kicad_sch, com_express_7_mgmt.kicad_sch, gpio_exp.kicad_sch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]
2024-10-23 [#57056] Change PCIe lanes
    [com-express-7-baseboard.kicad_sch]
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2024-10-23 [#57056] Remove AC coupling caps on PCIe lines
    [m2keye.kicad_sch, m2keym.kicad_sch]
2024-10-23 [#57498] Add SFP+ indicator LEDs
    [2xSFP+.kicad_sch, com-express-7-baseboard.kicad_sch, gpio_exp.kicad_sch]
2024-10-23 [#57498] Add SD card
    [com-express-7-baseboard.kicad_sch, com_express_7_interfaces.kicad_sch, sd_card.kicad_sch]
2024-10-23 [#57056] Add PCIe redriver for OCuLink
    [com-express-7-baseboard.kicad_sch, m2keye.kicad_sch, oculink.kicad_sch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]
2024-10-23 [#57056] Add backplane connector
    [backplane.kicad_sch, com-express-7-baseboard.kicad_sch, com_express_7_interfaces.kicad_sch]
2024-10-23 [#57905] Add power and reset circuitry
    [com_express_7_mgmt.kicad_sch]
2024-10-23 [#57905] Add Type 7 check
    [com_express_7_mgmt.kicad_sch]
2024-10-23 [#57905] Add MAFS carrier BIOS
    [com-express-7-baseboard.kicad_sch, com_express_7_interfaces.kicad_sch, com_express_7_mgmt.kicad_sch]
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2024-10-23 [#58137] Add power sequencing and reset
    [2xSFP+.kicad_sch, com-express-7-baseboard.kicad_sch, com_express_7_mgmt.kicad_sch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]
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2024-10-23 Fix ERC
    [backplane.kicad_sch, com-express-7-baseboard.kicad_sch, com_express_7_interfaces.kicad_sch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]
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2024-10-23 [#58137] Add power monitors; clean up I2C bus
    [com-express-7-baseboard.kicad_sch, com_express_7_mgmt.kicad_sch, misc.kicad_sch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]
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2024-10-23 [#58137] Add input voltage and buttons ESD protection
    [com_express_7_mgmt.kicad_sch, power.kicad_sch]
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2024-10-23 [#58571] Reset drill origin pos
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2024-10-23 [#58904] Change +5V load switch transistor to SI7613DN-T1-GE3
    [power.kicad_sch]
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2024-10-23 [#58904] Improve power and reset circuitry
2024-10-23 [#58904] Change pinout of backplane connector. Connect CLKREQ from PCIe devices
    [backplane.kicad_sch, com-express-7-baseboard.kicad_sch, m2keye.kicad_sch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]
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2024-10-23 [#58904] Fix DRC
    [2xSFP+.kicad_sch, backplane.kicad_sch, com-express-7-baseboard.kicad_sch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]
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2024-10-23 Fix component visualization issues
    [m2keye.kicad_sch]
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2024-10-23 [#65446] Add low profile M.2 key M connector, move M.2 drives
    [com-express-7-baseboard.kicad_sch, m2keym.kicad_sch, m2keym_low.kicad_sch]
2024-10-23 [#65446] Update the M.2 connector from the library
    [m2keym_low.kicad_sch]
2024-10-23 [#65447] Fix rotated LEDs, overlapping text and symbols, add rules
    [backplane.kicad_sch, com_express_7_interfaces.kicad_sch, com_express_7_mgmt.kicad_sch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]
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2024-10-23 [#65447] Flip REFCLK for easier routing
    [kr_sfi.kicad_sch]
2024-10-23 [#65447] Fix misaligned text
    [power.kicad_sch]
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2024-10-23 [#65447] Layout PCIe, fix net names
    [backplane.kicad_sch, misc.kicad_sch, oculink.kicad_sch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]
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2024-10-23 [#65840] Route PCIe clock fanout, improve PCIe lines layout
    [m2keym_low.kicad_sch, pcie_misc.kicad_sch]
2024-10-23 [#65840] Reroute PCIe lines near COM connector, to fit GND vias
    [m2keym_low.kicad_sch]
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2024-10-23 [#66234] Adjust ESD protection diodes, layout fan connectors
    [backplane.kicad_sch, com-express-7-baseboard.kicad_sch]
2024-10-23 [#66234] Layout OCuLink power, SFP, low speed signals
    [2xSFP+.kicad_sch]
2024-10-23 [#66613] Split EQ, FG and SW lines of PCIe redrivers, align PCIe, misc signals
    [pcie_redriver.kicad_sch]
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2024-10-23 [#66613] Change yellow LEDs from 0402 to 0603 package
    [2xSFP+.kicad_sch]
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2024-10-23 [#66613] Adjust silkscreen, move logos, layout power and reset circuitry
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2024-10-23 [#66613] Add more capacitors to SFP connector shield
    [2xSFP+.kicad_sch]
2024-10-23 [#66613] Fix ERC, adjust overlapping text on schematic
    [2xSFP+.kicad_sch, com_express_7_mgmt.kicad_sch, m2keym_low.kicad_sch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]
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2024-10-23 [#67124] Calculate LEDs resistors, fix 1V0 and 1V8 LED circuit
    [power.kicad_sch]
2024-10-23 [#67124] Change SFI bypass resistors and capacitors from 0402 to 0201
    [kr_sfi.kicad_sch]
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2024-10-23 [#67124] Make all vias have annular ring on top, bottom and connected layers only; update date
    [com_express_7_mgmt.kicad_sch]
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2024-11-06 [#67758] Add COM mounting standoffs, start rerouting tracks around them
    [com_express_7_interfaces.kicad_sch]
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2024-11-06 [#67758] Add missing GND vias for HS layer changes, adjust vias for GND pouring between them
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2024-11-06 [#67758] Mark CE7 mod. DNP; Add more TVS to J4
    [com_express_7_interfaces.kicad_sch, oculink.kicad_sch]
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2024-11-06 [#67758] Change power indicator LED's transistors to MMBT3904 to minimize BOM
    [power.kicad_sch]
2024-11-06 [#67758] Fix ERC - ignore pin not driven
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2024-11-06 [#67758] Fix issues reported by PCB fab
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2024-11-08 [#68429] Fix board name in mechanical subsection
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2024-11-20 [#68429] Fix typos and grammatical errors, add SFI/KR bypass description, mention USB in J100 M.2 connector
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2024-11-21 [#69069] Change DRC - copper to hole clearance 0.2 -> 0.25mm
2024-11-21 [#69069] Fix track to via clearance
2024-11-21 [#69069] Increase track to via clearance, allowing usage of vias connected on all layers
2024-11-21 [#69069] Fix 1V0 and 1V8 power indicator LEDs being swapped on the PCB
    [power.kicad_sch]
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2024-12-13 [#70030] Small silkscreen fixes
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2025-01-08 [#69944] Fix power button and autostartup on the schematic
    [com_express_7_mgmt.kicad_sch, power.kicad_sch]
2025-01-08 [#69944] Fix power button and autostartup on the PCB
2025-01-08 [#70532] Change Molex Nano-Fit connector from 105309-2202 to 105309-1202
    [power.kicad_sch]
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2025-01-09 [#70532] Increase D17 and D18 LED's resistors to 10k
    [misc.kicad_sch]
2025-01-09 [#70532] Update Lightpipe_Bivar_SLP3-300-250-F with corrected hole size
2025-01-10 [#70532] Fix RJ45 LEDs connection
    [usb3+rj45.kicad_sch]
2025-01-29 [#70532] Fix RJ45 GBE0_ACT LED logic
    [usb3+rj45.kicad_sch]
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2025-01-30 [#70532] Enable all PCIe clock outputs with resistors
    [pcie_misc.kicad_sch]
2025-01-30 [#70532] Fix USB SS pinout (J1)
    [usb3+rj45.kicad_sch]
2025-01-30 [#72360] Update date, remove GND teardrops under ICs
    [2xSFP+.kicad_sch, backplane.kicad_sch, com-express-7-baseboard.kicad_sch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]
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2025-01-31 [#72360] Fix power input connector polarity
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
